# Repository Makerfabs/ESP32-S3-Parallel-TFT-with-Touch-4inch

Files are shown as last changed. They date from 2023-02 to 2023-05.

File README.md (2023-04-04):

# Makerfabs ESP32-S3 Parallel TFT with Touch 4inch

```c++
/*
Version:        V1.1
Author:            Vincent
Create Date:    2023/2/4
Note:
        V1.2：Now support LovyanGFX！
        V1.1: Add example and update readme.
*/
```

[TOC]

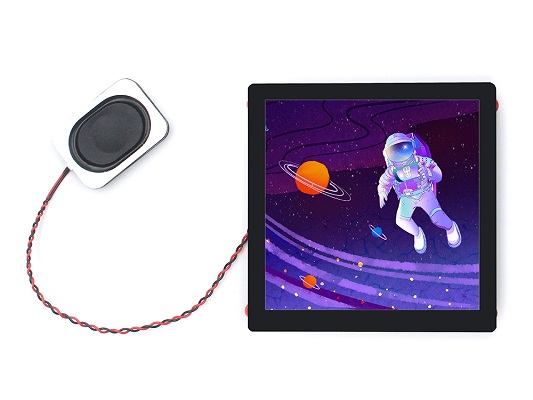
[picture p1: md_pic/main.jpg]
main


# Makerfabs

[Makerfabs home page](https://www.makerfabs.com/)

[Makerfabs Wiki](https://wiki.makerfabs.com/)

# Makerfabs ESP32-S3 Parallel TFT with Touch 4inch

## Intruduce

Product Link ：[ESP32-S3 Parallel TFT with Touch 4.0" 480*480 ST7701](https://www.makerfabs.com/esp32-s3-parallel-tft-with-touch-4-inch.html)

Wiki Link : [ESP32-S3 Parallel 4.0" TFT with Touch](https://wiki.makerfabs.com/ESP32_S3_Parallel_4.0_TFT_with_Touch.html)

The Latest ESP32-S3 4.0 inch display with 480*480 resolution, it integrated display/ touch/ audio speaker/ Lipo charger, to make this product ideal for applications such as IoT controlling, electronic photo frame, etc.

## Feature

- 4 inch RGB IPS display, it communicates with the controller ESP32S3 with 3SPI+RGB5/6/5 interface, with FPS >80;
- 5 points Touch;
- Onboard 16G SD card for storage;
- Lipo battery socket and charger, support any 3.7v lipo battery;
- On board speaker connector. This product is shipped with a 3 ohm 4w, 3528 speaker, the voice loud and clean, suitable for most applications;
- 2x Onboard Mabee connectors, support multiple Mabee/ Grove modules;

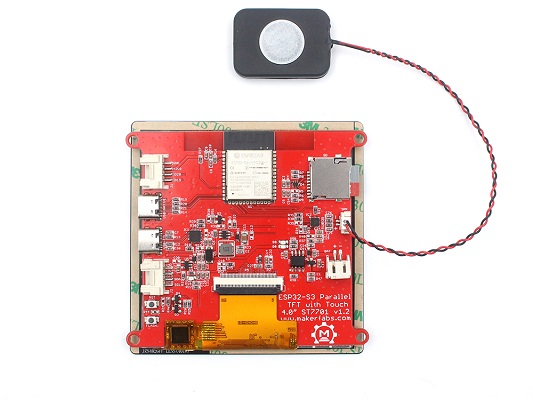
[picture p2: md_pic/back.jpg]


# Code

## Complier Option

- Install board : ESP32 .
- Install libraries：

[ESP32-audioI2S]([GitHub - schreibfaul1/ESP32-audioI2S: Play mp3 files from SD via I2S](https://github.com/schreibfaul1/ESP32-audioI2S))

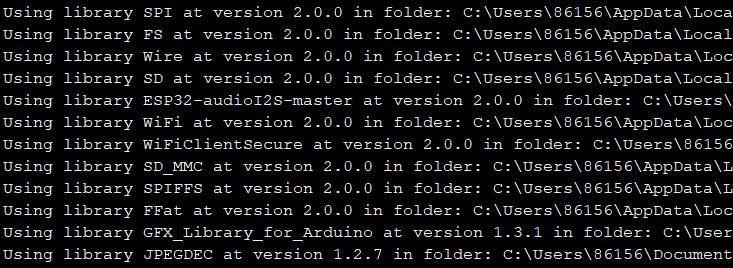
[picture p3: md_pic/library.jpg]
library


- Use type-c use cable connect USB-TTL to PC.
- Select "ESP32-S3 DEV Module"
- Select PSRAM "OPI PSRAM"

"mf_Lvgl" library is modified from Lvgl library (version 8.3.2). 

Please unzip "lib/mf_Lvgl.zip" and copy to arduino library directory.

## Factory test program

\example\esp32s3_4.0_tft_fw_test

You can run this file test if you feel that your hardware is not working properly. 

In addition, it is necessary to decompress the compressed package in the sd_file folder and copy all the pictures and music in it to the TF card.

## Attention

Our Arduino_GFX_library version is 1.3.1, while the latest version is 1.3.4. The two versions are incompatible the running code. Our customer@Tim successfully ran the Arduino_gfx_Library version after modifying the configuration in the code on version 1.3.4.

```
Arduino_DataBus *bus = new Arduino_SWSPI(
    GFX_NOT_DEFINED /* DC */, 1 /* CS */,
    12 /* SCK */, 11 /* MOSI */, GFX_NOT_DEFINED /* MISO */);

Arduino_ESP32RGBPanel *rgbpanel = new Arduino_ESP32RGBPanel(
    45 /* DE */, 4 /* VSYNC */, 5 /* HSYNC */, 21 /* PCLK */,
    39 /* R0 */, 40 /* R1 */, 41 /* R2 */, 42 /* R3 */, 2 /* R4 */,
    0 /* G0 */, 9 /* G1 */, 14 /* G2 */, 47 /* G3 */, 48 /* G4 */, 3 /* G5 */,
    6 /* B0 */, 7 /* B1 */, 15 /* B2 */, 16 /* B3 */, 8 /* B4 */,
    1 /* hsync_polarity */, 10 /* hsync_front_porch */, 8 /* hsync_pulse_width */, 50 /* hsync_back_porch */,
    1 /* vsync_polarity */, 10 /* vsync_front_porch */, 8 /* vsync_pulse_width */, 20 /* vsync_back_porch */);

Arduino_RGB_Display *gfx = new Arduino_RGB_Display(
    480 /* width */, 480 /* height */, rgbpanel, 0 /* rotation */, true /* auto_flush */,
    bus, GFX_NOT_DEFINED /* RST */, st7701_type1_init_operations, sizeof(st7701_type1_init_operations));
```

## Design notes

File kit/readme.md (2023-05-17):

# Makerfabs ESP32-S3 4" Kit

```c++
/*
Version:        V1.1
Author:         Vincent
Create Date:    2023/3/14
Note:

    2023/5/15    V1.1：Change weather API and icons.
*/
```

# Makerfabs

[Makerfabs home page](https://www.makerfabs.com/)

[Makerfabs Wiki](https://wiki.makerfabs.com/)

# Makerfabs ESP32-S3 Parallel TFT with Touch 4inch

## Intruduce

Product Link ：[ESP32-S3 Parallel TFT with Touch 4.0" 480*480 ST7701](https://www.makerfabs.com/esp32-s3-parallel-tft-with-touch-4-inch.html)

Wiki Link : [ESP32-S3 Parallel 4.0" TFT with Touch](https://wiki.makerfabs.com/ESP32_S3_Parallel_4.0_TFT_with_Touch.html)

# 

# Usage

## SD card prepare

Extract "\ESP32-S3-Parallel-TFT-with-Touch-4inch\kit\sd_file.zip"

Copy all files in sd_file to the SD card, making sure that wifi.txt,mp3,jpg are in the root directory.

The SD card shipped with the factory has already downloaded the necessary files.

Of course you can put your pictures and music on the SD card.

The image should be in.jpg format, preferably 480 by 480 pixels.

Music required format.mp3.

And edit "wifi.txt", change your own WiFi ssid and WiFi password.

```
SSID:[YOUR SSID]
PASSWORD:[YOUR PWD]
# Please change your own wifi setting in "[]".
# WIFI name and password can only contain letters and numbers, the program is not fully compatible with special characters.
```

Insert SD card.

## Music Frame

JPG pictures and MP3 music in the root directory of the SD card are automatically played.

## Global Weather

Click on the flags of different countries to toggle different periods and show the weather in the capital.

## TVOC Monitor

Mabee CO2 needs to be connected to the I2C interface.

Displays TVOC sensor measurements and provides a web page to access.

You need to set up WiFi to use it.

## Thermal Camera

You need to connect Mabee MLX90640 to the I2C interface

Simple thermal imaging camera.

# Code

## Bin Burn

Select ESP32 S3

0x0                    kit.ino.bootloader.bin 
0x8000             kit.ino.partitions.bin 
0xe000             boot_app0.bin 
0x10000           kit.ino.bin 

## Complier Option

Install board : ESP32 2.0.5

Install libraries from Library Manager：

- Using 1.3.1  Version  GFX_Library_for_Arduino

- Using 1.0.2  Version  TAMC_GT911

- Using 6.20.1  Version  ArduinoJson

- Using 1.0.2  Version  Adafruit_MLX90640

- Using 1.14.1  Version  Adafruit_BusIO

- Using 2.0.0  Version  Adafruit_SGP30_Sensor

- Using 2.2.0  Version  Adafruit_SHT31_Library

- Using 1.2.8  Version  JPEGDEC

Install libraries from Github：

- Using 2.0.0  Version  ESP32-audioI2S-master

- Using 1.2.3  Version  ESPAsyncWebServer-masterr 

- Using 1.1.1  Version  AsyncTCP-master

Use type-c use cable connect USB-TTL to PC.

Select "ESP32-S3 DEV Module"

Select PSRAM "OPI PSRAM"

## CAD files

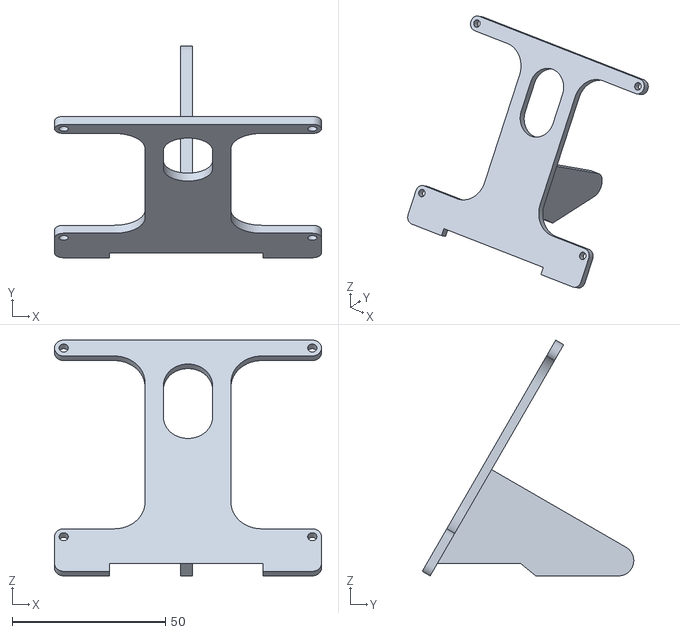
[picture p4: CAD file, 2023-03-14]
kit/3d_file/stand.stl
87.0 x 68.9 x 76.8

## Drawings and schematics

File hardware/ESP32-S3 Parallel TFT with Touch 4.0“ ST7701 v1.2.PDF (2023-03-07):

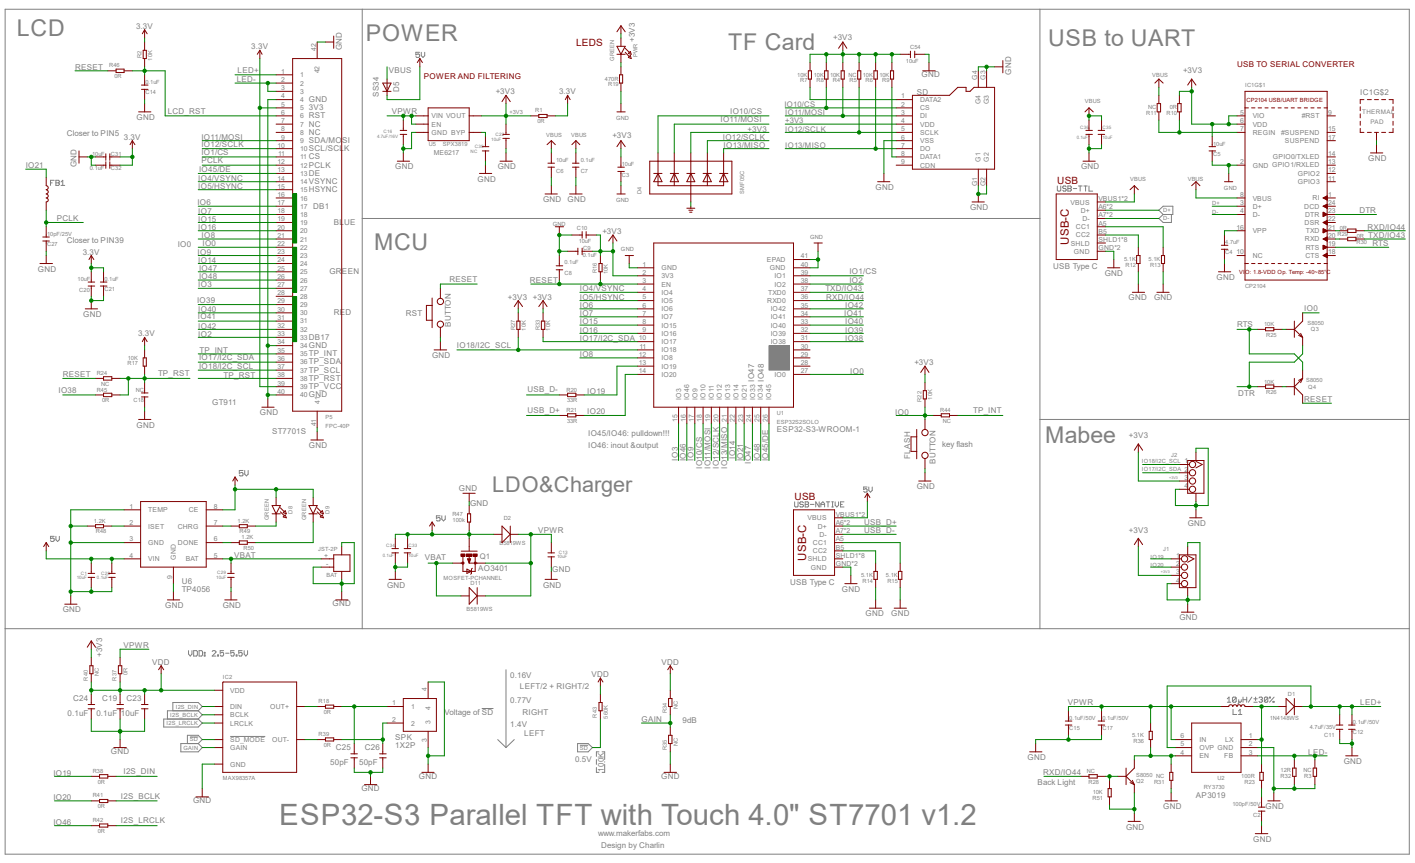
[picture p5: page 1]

USB Type C TF Card

USB TO SERIAL CONVERTER

VIO: 1.8-VDD Op. Temp: -40~85°C USB⁻C USB⁻C

key flash ESP32-S3 Parallel TFT with Touch 4.0" ST7701 v1.2

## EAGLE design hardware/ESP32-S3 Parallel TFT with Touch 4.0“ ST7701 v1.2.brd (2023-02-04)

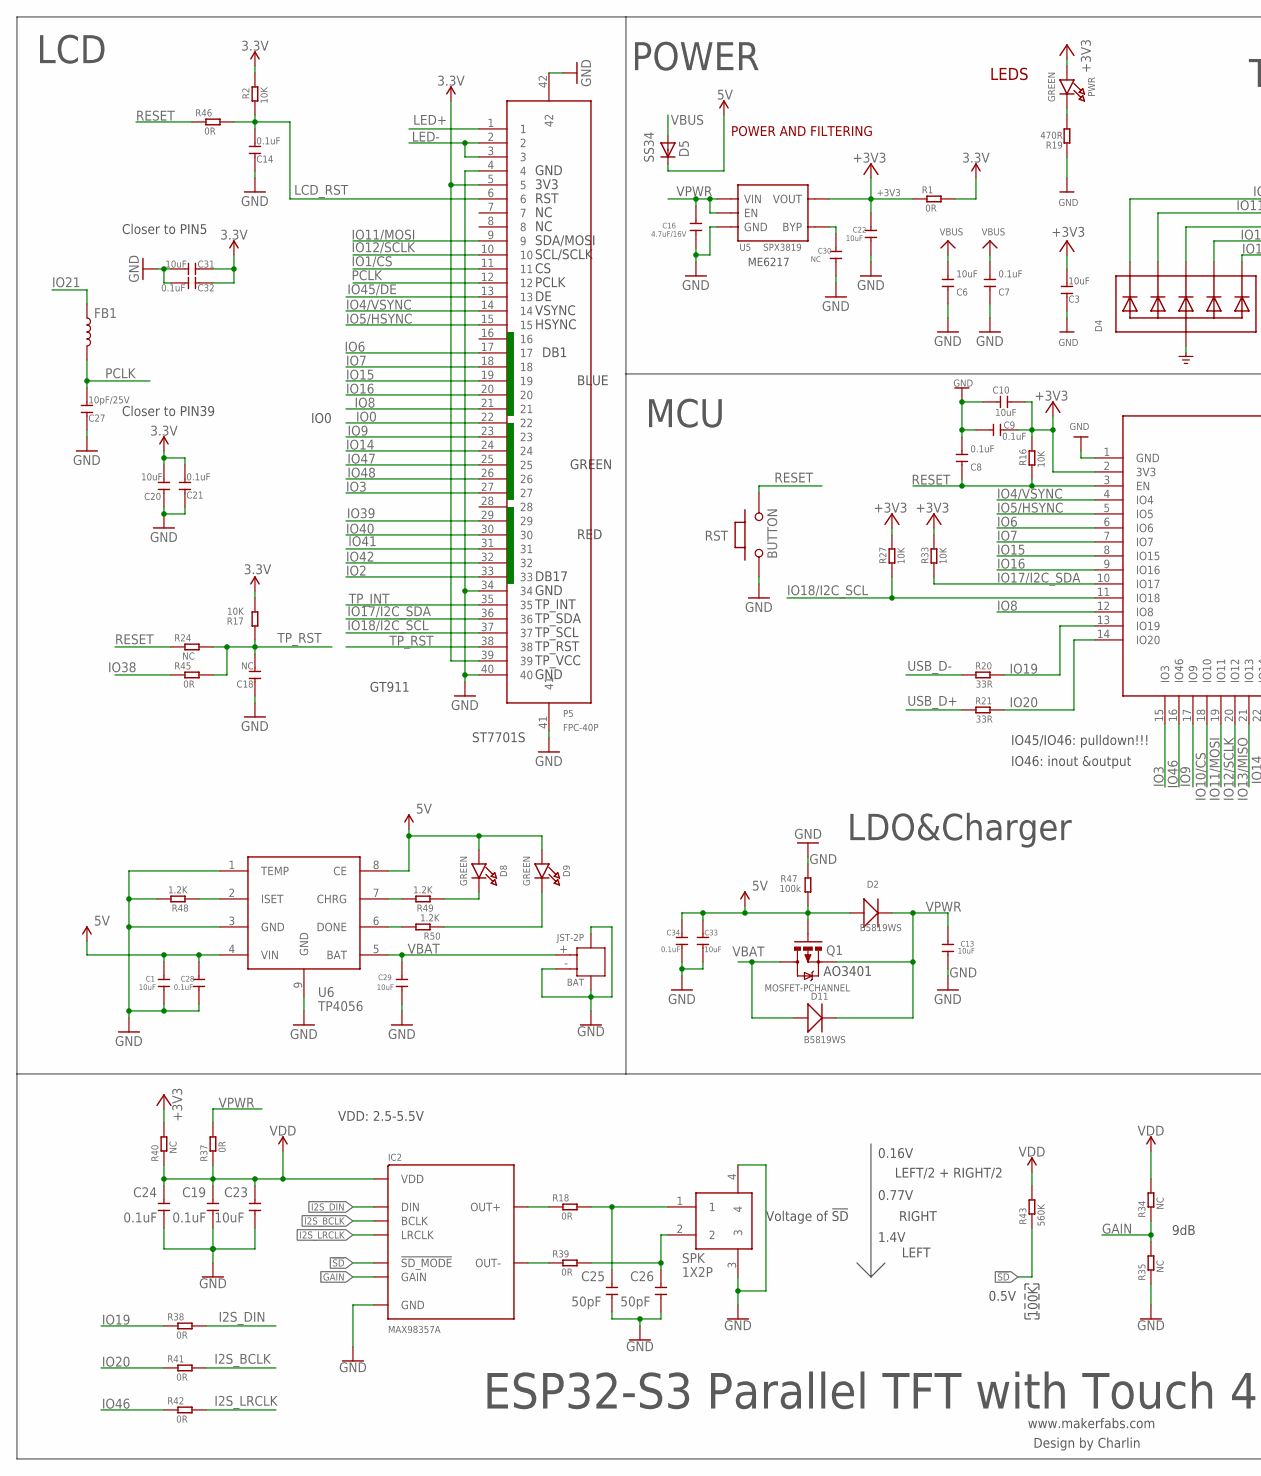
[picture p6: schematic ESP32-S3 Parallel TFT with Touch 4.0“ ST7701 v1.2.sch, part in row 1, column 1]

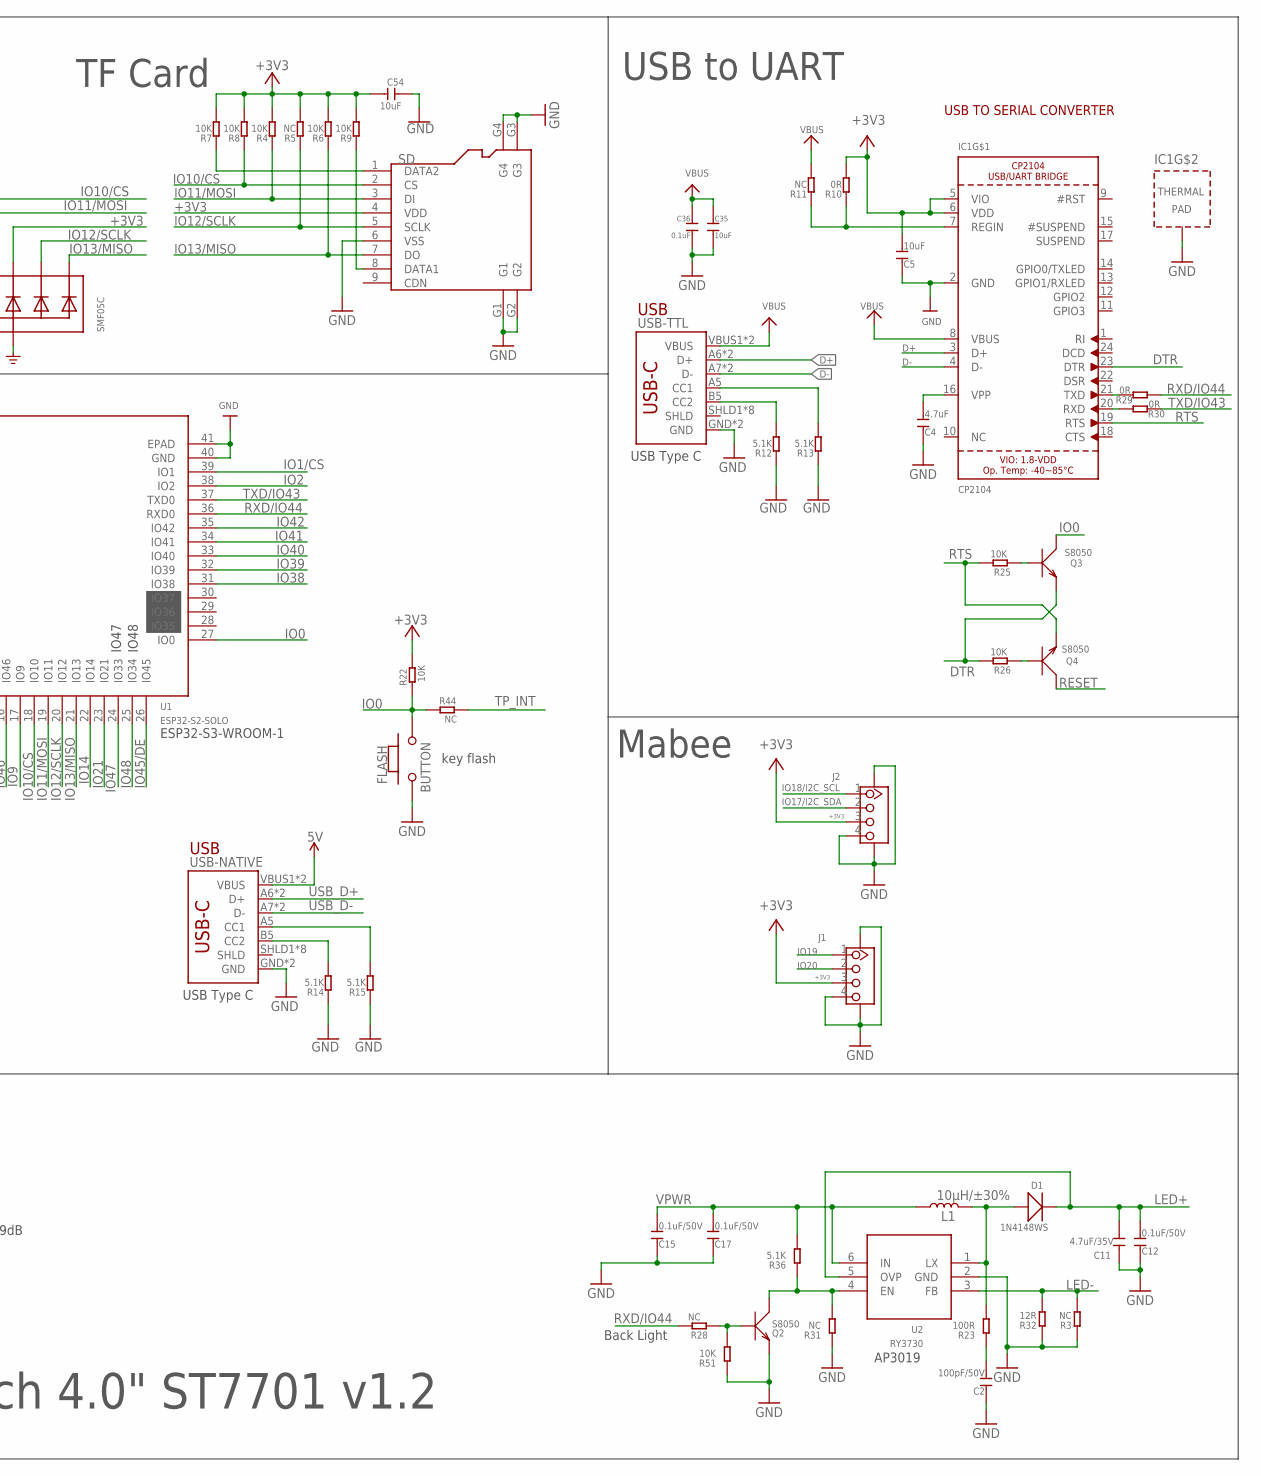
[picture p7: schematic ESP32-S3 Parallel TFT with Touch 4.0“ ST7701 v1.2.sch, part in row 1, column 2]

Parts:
BAT: JST-2P; HW2-SMD-2.0-90D
C1, C13, C22, C23, C29, C33, C35: 10uF; 0603
C2: 100pF/50V; DISCRETE_C0603
C3, C5, C6, C10, C20, C31, C54: 10uF; DISCRETE_C0603
C4: 4.7uF; DISCRETE_C0603
C7, C8, C9, C14, C21, C32: 0.1uF; DISCRETE_C0603
C11: 4.7uF/35V; DISCRETE_C1206
C12, C15, C17: 0.1uF/50V; DISCRETE_C0603
C16: 4.7uF/16V; 0603
C18: NC; DISCRETE_C0603
C19, C24, C28, C34, C36: 0.1uF; 0603
C25, C26: 50pF; 0603
C27: 10pF/25V; DISCRETE_C0603
C30: NC; 0603
D1: 1N4148WS; SOD323
D2, D11: B5819WS; SOD323
D4: SMF05C; SOT363
D5: SS34; DO-214AC
D8, D9: GREEN; CHIPLED_0805_NOOUTLINE
FB1: INDUCTORFB-30OHM; 0603
FLASH: BUTTON; 157SW
IC1: CP2104; QFN24_4MM_SMSC
IC2: MAX98357A; TQFN-16
J1, J2: GROVE-CONNECTOR-SMD'90D'; HW4-SMD-2.0-90D
L1: 10µH/±30%; CR54
P5: FPC-40P; SMD42-50P-2560L490W
PWR: GREEN; CHIPLED_0805_NOOUTLINE
Q1: MOSFET-PCHANNEL; SOT23-3
Q2, Q3, Q4: S8050; SOT23
R1, R18, R29, R30, R37, R38, R39, R41, R42, R45, R46: 0R; R0603
R2, R16, R22, R25, R26, R27, R33: 10K; R0603
R3, R5, R11, R28, R31: NC; DISCRETE_R0603
R4, R6, R7, R8, R9, R17, R51: 10K; DISCRETE_R0603
R10: 0R; DISCRETE_R0603
R12, R13, R14, R15, R36: 5.1K; DISCRETE_R0603
R19: 470R; DISCRETE_R0603
R20, R21: 33R; R0603
R23: 100R; DISCRETE_R0603
R24, R34, R35, R40, R44: NC; R0603
R32: 12R; DISCRETE_R0603
R43: 560K; R0603
R47: 100k; R0603
R48, R49, R50: 1.2K; R0603
RST: BUTTON; 157SW
SD: HOLDER-MICROSD-9P; 9P-SMD-W/-RING
SPK: 1X2P; 1X2P-SMT1.25MM
U1: ESP32­S2­SOLO; ESP32-­S2-­SOLO
U2: RY3730; SOT23-6
U5: SPX3819; SOT23-5
U6: TP4056; SOP8-1.27P
USB-NATIVE: USB_C5; USB-C-16P-5
USB-TTL: USB_C5; USB-C-16P-5

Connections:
3.3V: C20.2, C21.2, C31.1, C32.1, P5.5, P5.39, R1.2, R2.2, R17.2
5V: C1.1, C28.1, C33.2, C34.1, D2.+, D5.C, D8.A, D9.A, Q1.1 (G), R47.1, U6.4 (VIN), U6.8 (CE), USB-NATIVE.VBUS1 (VBUS), USB-NATIVE.VBUS2 (VBUS)
!SD: IC2.P$4 (!SD_MODE), R43.1
+3V3: C3.2, C5.2, C9.1, C10.1, C22.1, C54.2, D4.4 (C3), IC1.5 (VIO), IC1.6 (VDD), J1.3, J2.3, PWR.A, R1.1, R4.2, R5.2, R6.2, R7.2, R8.2, R9.2, R10.2, R16.2, R22.2, R27.2, R33.2, R40.2, SD.4 (VDD), U1.2 (3V3), U5.5 (VOUT)
D+: IC1.3 (D+), USB-TTL.A6 (D+), USB-TTL.B6 (D+)
D-: IC1.4 (D-), USB-TTL.A7 (D-), USB-TTL.B7 (D-)
DTR: IC1.23 (DTR), Q3.2 (E), R26.2
GAIN: IC2.P$2 (GAIN), R34.1, R35.2
GND: BAT.3, BAT.4, BAT.- (2), C1.2, C2.1, C3.1, C4.1, C5.1, C6.1, C7.1, C8.2, C9.2, C10.2, C11.1, C12.1, C13.1, C14.1, C15.1, C16.2, C17.1, C18.1, C19.1, C20.1, C21.1, C22.2, C23.1, C24.1, C25.1, C26.1, C27.1, C28.2, C29.2, C30.2, C31.2, C32.2, C33.1, C34.2, C35.1, C36.2, C54.1, D4.2 (A), FLASH.1, IC1.2 (GND), IC1.THERM (TP), IC2.P$3 (GND), IC2.P$11 (GND), IC2.P$15 (GND), IC2.P$EP (GND), J1.4, J1.SS1, J1.SS2, J2.4, J2.SS1, J2.SS2, P5.4, P5.34, P5.40, P5.41, P5.42, Q2.2 (E), R3.1, R12.1, R13.1, R14.1, R15.1, R19.1, R31.1, R32.1, R35.1, R47.2, R48.2, R51.1, RST.1, SD.6 (VSS), SD.G1, SD.G2, SD.G3, SD.G4, SPK.3, SPK.4, U1.1 (GND), U1.40 (GND), U1.41 (EPAD), U2.2 (GND), U5.2 (GND), U6.1 (TEMP), U6.3 (GND), U6.9 (GND), USB-NATIVE.GND, USB-NATIVE.GND2 (GND), USB-TTL.GND, USB-TTL.GND2 (GND)
I2S_BCLK: IC2.P$16 (BCLK), R41.2
I2S_DIN: IC2.P$1 (DIN), R38.2
I2S_LRCLK: IC2.P$14 (LRCLK), R42.2
IO0: FLASH.2, P5.22, Q3.3 (C), R22.1, R44.1, U1.27 (IO0)
IO1/CS: P5.11, U1.39 (IO1)
IO2: P5.33, U1.38 (IO2)
IO3: P5.27, U1.15 (IO3)
IO4/VSYNC: P5.14, U1.4 (IO4)
IO5/HSYNC: P5.15, U1.5 (IO5)
IO6: P5.17, U1.6 (IO6)
IO7: P5.18, U1.7 (IO7)
IO8: P5.21, U1.12 (IO8)
IO9: P5.23, U1.17 (IO9)
IO10/CS: D4.1 (C1), R8.1, SD.2 (CS), U1.18 (IO10)
IO11/MOSI: D4.3 (C2), P5.9, R4.1, SD.3 (DI), U1.19 (IO11)
IO12/SCLK: D4.5 (C4), P5.10, R5.1, SD.5 (SCLK), U1.20 (IO12)
IO13/MISO: D4.6 (C5), R6.1, SD.7 (DO), U1.21 (IO13)
IO14: P5.24, U1.22 (IO14)
IO15: P5.19, U1.8 (IO15)
IO16: P5.20, U1.9 (IO16)
IO17/I2C_SDA: J2.2, P5.36, R33.1, U1.10 (IO17)
IO18/I2C_SCL: J2.1, P5.37, R27.1, U1.11 (IO18)
IO19: J1.1, R20.2, R38.1, U1.13 (IO19)
IO20: J1.2, R21.2, R41.1, U1.14 (IO20)
IO21: FB1.1, U1.23 (IO21)
IO38: R45.1, U1.31 (IO38)
IO39: P5.29, U1.32 (IO39)
IO40: P5.30, U1.33 (IO40)
IO41: P5.31, U1.34 (IO41)
IO42: P5.32, U1.35 (IO42)
IO45/DE: P5.13, U1.26 (IO45)
IO46: R42.1, U1.16 (IO46)
IO47: P5.25, U1.24 (IO33)
IO48: P5.26, U1.25 (IO34)
LCD_RST: C14.2, P5.6, R2.1, R46.2
LED+: C11.2, C12.2, D1.-, P5.1, U2.5 (OVP)
LED-: P5.2, P5.3, R3.2, R32.2, U2.3 (FB)
unnamed: C4.2, IC1.16 (VPP)
unnamed: Q4.1 (B), R26.1
unnamed: Q3.1 (B), R25.1
unnamed: IC2.P$9 (OUT+), R18.1
unnamed: R15.2, USB-NATIVE.A5 (CC1)
unnamed: PWR.C, R19.2
unnamed: Q2.1 (B), R28.1, R51.2
unnamed: R13.2, USB-TTL.A5 (CC1)
unnamed: R12.2, USB-TTL.B5 (CC2)
unnamed: IC1.7 (REGIN), R10.1, R11.1
unnamed: IC2.P$10 (OUT-), R39.1
unnamed: R14.2, USB-NATIVE.B5 (CC2)
unnamed: C25.2, R18.2, SPK.1
unnamed: C26.2, R39.2, SPK.2
unnamed: D1.+, L1.P$2 (2), R23.2, U2.1 (LX)
unnamed: IC1.21 (TXD), R29.2
unnamed: IC1.20 (RXD), R30.2
unnamed: C2.2, R23.1
unnamed: R48.1, U6.2 (ISET)
unnamed: Q2.3 (C), R31.2, R36.1, U2.4 (EN)
unnamed: R49.2, U6.7 (CHRG)
unnamed: R50.2, U6.6 (DONE)
unnamed: D8.C, R49.1
unnamed: D9.C, R50.1
unnamed: R7.1, SD.1 (DATA2)
unnamed: R9.1, SD.8 (DATA1)
unnamed: C30.1, U5.4 (BYP)
PCLK: C27.2, FB1.2, P5.12
RESET: C8.1, Q4.3 (C), R16.1, R24.1, R46.1, RST.2, U1.3 (EN)
RTS: IC1.19 (RTS), Q4.2 (E), R25.2
RXD/IO44: R28.2, R29.1, U1.36 (RXD0)
TP_INT: P5.35, R44.2
TP_RST: C18.2, P5.38, R17.1, R24.2, R45.2
TXD/IO43: R30.1, U1.37 (TXD0)
USB_D+: R21.1, USB-NATIVE.A6 (D+), USB-NATIVE.B6 (D+)
USB_D-: R20.1, USB-NATIVE.A7 (D-), USB-NATIVE.B7 (D-)
VBAT: BAT.+ (1), C29.1, D11.+, Q1.3 (D), U6.5 (BAT)
VBUS: C6.2, C7.2, C35.2, C36.1, D5.A, IC1.8 (VBUS), R11.2, USB-TTL.VBUS1 (VBUS), USB-TTL.VBUS2 (VBUS)
VDD: C19.2, C23.2, C24.2, IC2.P$7 (VDD), IC2.P$8 (VDD), R34.2, R37.1, R40.1, R43.2
VPWR: C13.2, C15.2, C16.1, C17.2, D2.-, D11.-, L1.P$1 (1), Q1.2 (S), R36.2, R37.2, U2.6 (IN), U5.1 (VIN), U5.3 (EN)

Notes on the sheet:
www.makerfabs.com
Design by Charlin
USB
LEDS
POWER AND FILTERING
USB TO SERIAL CONVERTER
key flash
ESP32-S3 Parallel TFT with Touch 4.0" ST7701 v1.2
POWER
USB to UART
USB Type C
TF Card
GT911
Back Light
IO45/IO46: pulldown!!!
IO46: inout &output
Mabee
LCD
MCU
ESP32-S3-WROOM-1
IO47
IO48
Closer to PIN5
3V3
DB1
RST
TP_INT
SDA/MOSI
SCL/SCLK
PCLK
VSYNC
HSYNC
TP_SDA
TP_SCL
TP_RST
TP_VCC
ST7701S
GND
DB17
BLUE

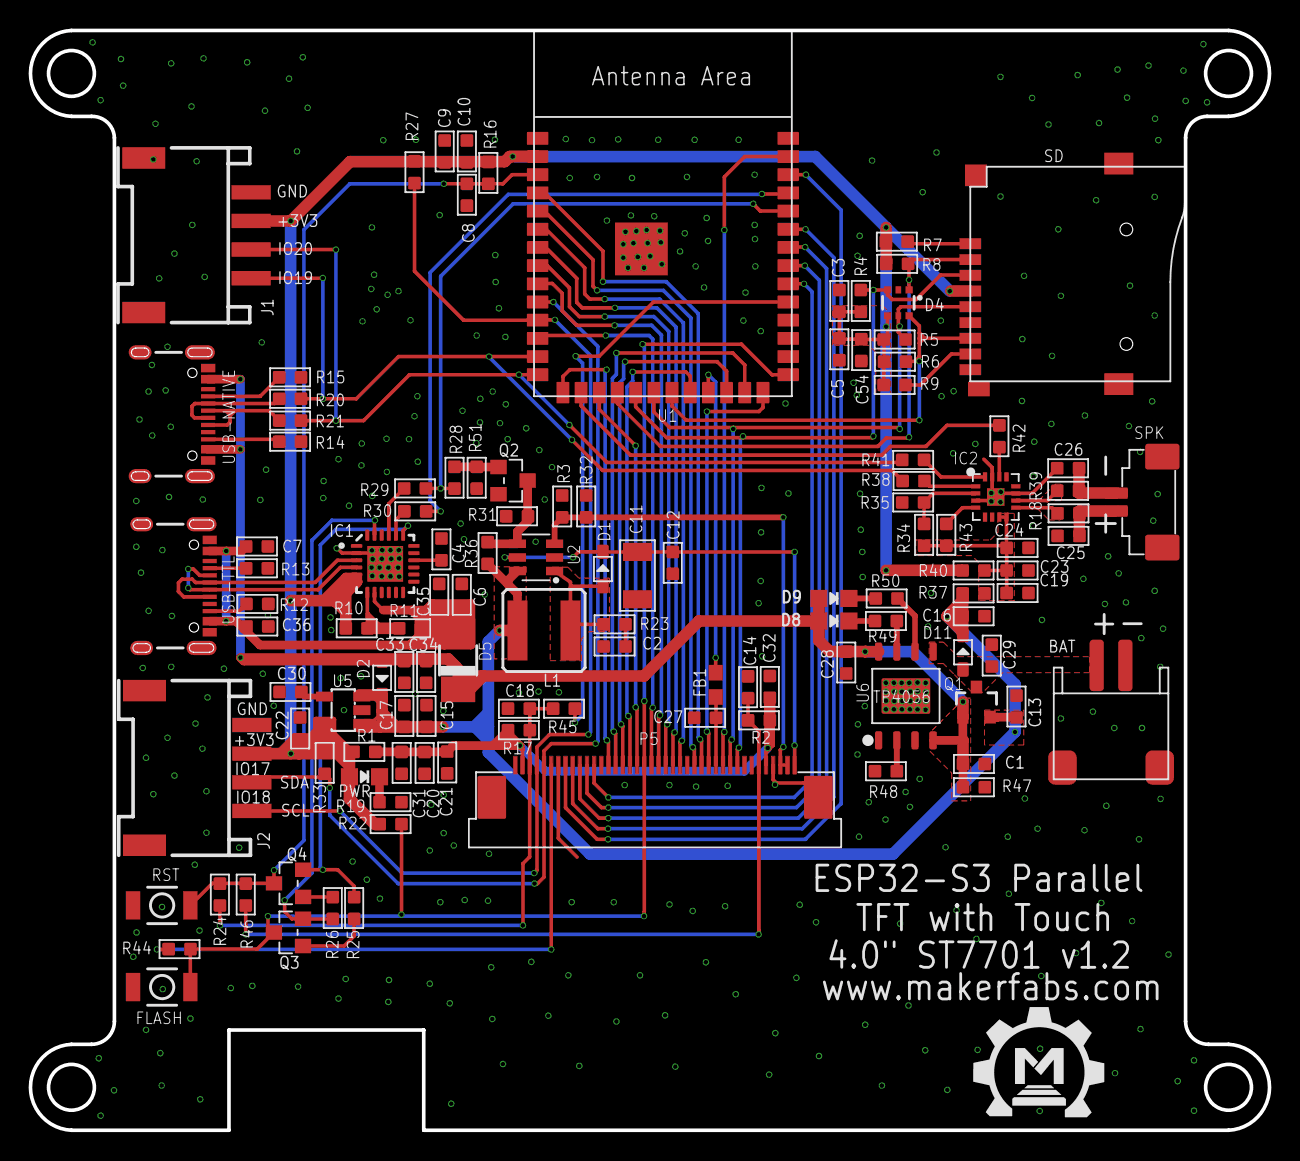
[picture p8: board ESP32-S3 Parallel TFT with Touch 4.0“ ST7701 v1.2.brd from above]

Board: 2 copper layers, 86.5 x 76.8 mm, 119 parts (0 on the bottom side), 86 nets.

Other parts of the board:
U$1: MAKERFABS_0.3

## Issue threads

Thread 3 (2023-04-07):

Arduino_ST7701_RGBPanel library missing?

puddletowntom, 2023-04-07:
I cant seem to find the ST7701 library. Are you sure its in your github repository.

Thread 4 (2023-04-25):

rotation values 1 and 3 do not work

rajiv-obhcare, 2023-04-25:
```
Arduino_ST7701_RGBPanel *gfx = new Arduino_ST7701_RGBPanel(
    bus, GFX_NOT_DEFINED /* RST */, 0 /* rotation */, true /* IPS */,
    480 /* width */, 480 /* height */, st7701_type1_init_operations,
    sizeof(st7701_type1_init_operations), true /* BGR */);

```

In the above code, of the 4 rotation values 0,1,2,3. Only 0 and 2 works. 3 and 4 do not work. How do I fix it?

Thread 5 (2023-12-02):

Compiling LVGL Example on Mac OSX

j-raghavan, 2023-12-02:
Hello,

I recently purchased ESP32-S3 Parallel TFT 4 inch ST7701, I am trying to compile the Example on Mac OSX and I fail to get it compile. Getting myriad of issues. Like these

```
In file included from /Users/jayasimha/Documents/Arduino/libraries/GFX_Library_for_Arduino/src/Arduino_GFX_Library.h:4,
                 from /Users/jayasimha/Workspace/arduino/playground/esp32/ESP32-S3-Parallel-TFT-with-Touch-4inch/example/esp32s3_4.0_tft_fw_test/esp32s3_4.0_tft_fw_test.ino:6:
/Users/jayasimha/Documents/Arduino/libraries/GFX_Library_for_Arduino/src/Arduino_DataBus.h:182:13: error: 'i80_device_list' has not been declared
  182 |   LIST_HEAD(i80_device_list, lcd_panel_io_i80_t)
      |             ^~~~~~~~~~~~~~~
/Users/jayasimha/Documents/Arduino/libraries/GFX_Library_for_Arduino/src/Arduino_DataBus.h:182:3: error: ISO C++ forbids declaration of 'LIST_HEAD' with no type [-fpermissive]
  182 |   LIST_HEAD(i80_device_list, lcd_panel_io_i80_t)
      |   ^~~~~~~~~
/Users/jayasimha/Documents/Arduino/libraries/GFX_Library_for_Arduino/src/Arduino_DataBus.h:182:48: error: expected ';' at end of member declaration
  182 |   LIST_HEAD(i80_device_list, lcd_panel_io_i80_t)
      |                                                ^
      |                                                 ;
/Users/jayasimha/Documents/Arduino/libraries/GFX_Library_for_Arduino/src/Arduino_DataBus.h:183:3: error: 'device_list' does not name a type
  183 |   device_list; // Head of i80 device list
      |   ^~~~~~~~~~~
/Users/jayasimha/Documents/Arduino/libraries/GFX_Library_for_Arduino/src/Arduino_DataBus.h:217:3: error: ISO C++ forbids declaration of 'LIST_ENTRY' with no type [-fpermissive]
  217 |   LIST_ENTRY(lcd_panel_io_i80_t)
      |   ^~~~~~~~~~
/Users/jayasimha/Documents/Arduino/libraries/GFX_Library_for_Arduino/src/Arduino_DataBus.h:217:32: error: expected ';' at end of member declaration
  217 |   LIST_ENTRY(lcd_panel_io_i80_t)
      |                                ^
      |                                 ;
/Users/jayasimha/Documents/Arduino/libraries/GFX_Library_for_Arduino/src/Arduino_DataBus.h:218:3: error: 'device_list_entry' does not name a type
  218 |   device_list_entry; // Entry of i80 device list
      |   ^~~~~~~~~~~~~~~~~
In file included from /Users/jayasimha/Documents/Arduino/libraries/GFX_Library_for_Arduino/src/Arduino_GFX_Library.h:19:
/Users/jayasimha/Documents/Arduino/libraries/GFX_Library_for_Arduino/src/databus/Arduino_ESP32RGBPanel.h:43:3: error: 'esp_lcd_rgb_panel_frame_trans_done_cb_t' does not name a type; did you mean 'esp_lcd_panel_io_color_trans_done_cb_t'?
   43 |   esp_lcd_rgb_panel_frame_trans_done_cb_t on_frame_trans_done; // Callback, invoked after frame trans done
      |   ^~~~~~~~~~~~~~~~~~~~~~~~~~~~~~~~~~~~~~~
      |   esp_lcd_panel_io_color_trans_done_cb_t
/Users/jayasimha/Workspace/arduino/playground/esp32/ESP32-S3-Parallel-TFT-with-Touch-4inch/example/esp32s3_4.0_tft_fw_test/esp32s3_4.0_tft_fw_test.ino:70:1: error: no matching function for call to 'Arduino_ESP32RGBPanel::Arduino_ESP32RGBPanel(int, int, int, int, int, int, int, int, int, int, int, int, int, int, int, int, int, int, int, int, int, int, int)'
   70 | );
      | ^
/Users/jayasimha/Documents/Arduino/libraries/GFX_Library_for_Arduino/src/databus/Arduino_ESP32RGBPanel.h:59:3: note: candidate: 'Arduino_ESP32RGBPanel::Arduino_ESP32RGBPanel(int8_t, int8_t, int8_t, int8_t, int8_t, int8_t, int8_t, int8_t, int8_t, int8_t, int8_t, int8_t, int8_t, int8_t, int8_t, int8_t, int8_t, int8_t, int8_t, int8_t, uint16_t, uint16_t, uint16_t, uint16_t, uint16_t, uint16_t, uint16_t, uint16_t, uint16_t, int32_t, bool, uint16_t, uint16_t)'
   59 |   Arduino_ESP32RGBPanel(
      |   ^~~~~~~~~~~~~~~~~~~~~
/Users/jayasimha/Documents/Arduino/libraries/GFX_Library_for_Arduino/src/databus/Arduino_ESP32RGBPanel.h:59:3: note:   candidate expects 33 arguments, 23 provided
/Users/jayasimha/Documents/Arduino/libraries/GFX_Library_for_Arduino/src/databus/Arduino_ESP32RGBPanel.h:56:7: note: candidate: 'constexpr Arduino_ESP32RGBPanel::Arduino_ESP32RGBPanel(const Arduino_ESP32RGBPanel&)'
   56 | class Arduino_ESP32RGBPanel
      |       ^~~~~~~~~~~~~~~~~~~~~
/Users/jayasimha/Documents/Arduino/libraries/GFX_Library_for_Arduino/src/databus/Arduino_ESP32RGBPanel.h:56:7: note:   candidate expects 1 argument, 23 provided
/Users/jayasimha/Documents/Arduino/libraries/GFX_Library_for_Arduino/src/databus/Arduino_ESP32RGBPanel.h:56:7: note: candidate: 'constexpr Arduino_ESP32RGBPanel::Arduino_ESP32RGBPanel(Arduino_ESP32RGBPanel&&)'
/Users/jayasimha/Documents/Arduino/libraries/GFX_Library_for_Arduino/src/databus/Arduino_ESP32RGBPanel.h:56:7: note:   candidate expects 1 argument, 23 provided
/Users/jayasimha/Workspace/arduino/playground/esp32/ESP32-S3-Parallel-TFT-with-Touch-4inch/example/esp32s3_4.0_tft_fw_test/esp32s3_4.0_tft_fw_test.ino:72:1: error: 'Arduino_ST7701_RGBPanel' does not name a type; did you mean 'Arduino_ESP32RGBPanel'?
   72 | Arduino_ST7701_RGBPanel *gfx = new Arduino_ST7701_RGBPanel(
      | ^~~~~~~~~~~~~~~~~~~~~~~
      | Arduino_ESP32RGBPanel
/Users/jayasimha/Workspace/arduino/playground/esp32/ESP32-S3-Parallel-TFT-with-Touch-4inch/example/esp32s3_4.0_tft_fw_test/esp32s3_4.0_tft_fw_test.ino: In function 'int jpegDrawCallback(JPEGDRAW*)':
/Users/jayasimha/Workspace/arduino/playground/esp32/ESP32-S3-Parallel-TFT-with-Touch-4inch/example/esp32s3_4.0_tft_fw_test/esp32s3_4.0_tft_fw_test.ino:122:3: error: 'gfx' was not declared in this scope
  122 |   gfx->draw16bitBeRGBBitmap(pDraw->x, pDraw->y, pDraw->pPixels, pDraw->iWidth, pDraw->iHeight);
      |   ^~~
/Users/jayasimha/Workspace/arduino/playground/esp32/ESP32-S3-Parallel-TFT-with-Touch-4inch/example/esp32s3_4.0_tft_fw_test/esp32s3_4.0_tft_fw_test.ino: In function 'void imageDisplay(int)':
/Users/jayasimha/Workspace/arduino/playground/esp32/ESP32-S3-Parallel-TFT-with-Touch-4inch/example/esp32s3_4.0_tft_fw_test/esp32s3_4.0_tft_fw_test.ino:149:38: error: 'gfx' was not declared in this scope
  149 |                0 /* x */, 0 /* y */, gfx->width() /* widthLimit */, gfx->height() /* heightLimit */);
      |                                      ^~~
/Users/jayasimha/Workspace/arduino/playground/esp32/ESP32-S3-Parallel-TFT-with-Touch-4inch/example/esp32s3_4.0_tft_fw_test/esp32s3_4.0_tft_fw_test.ino: In function 'void setup()':
/Users/jayasimha/Workspace/arduino/playground/esp32/ESP32-S3-Parallel-TFT-with-Touch-4inch/example/esp32s3_4.0_tft_fw_test/esp32s3_4.0_tft_fw_test.ino:225:3: error: 'gfx' was not declared in this scope
  225 |   gfx->begin();
      |   ^~~
Multiple libraries were found for "SD.h"
  Used: /Users/jayasimha/Library/Arduino15/packages/esp32/hardware/esp32/3.0.0-alpha2/libraries/SD
  Not used: /Users/jayasimha/Library/Arduino15/libraries/SDOLD
exit status 1

Compilation error: no matching function for call to 'Arduino_ESP32RGBPanel::Arduino_ESP32RGBPanel(int, int, int, int, int, int, int, int, int, int, int, int, int, int, int, int, int, int, int, int, int, int, int)'
```

Could some one help me point to a guide that can help me compile the sample code and help me get started developing on this board?

Thanks,
JR

rubenvillarnet, 2023-12-07:
I'm having the exact issues as @j-raghavan. This is my environment info:
- OS: macOS 12.7.1
- Arduino IDE 2.2.1
- I've followed the steps of this guide: [https://wiki.makerfabs.com/MaTouch_S3_Parallel_4.0_TFT_with_Touch.html](https://wiki.makerfabs.com/MaTouch_S3_Parallel_4.0_TFT_with_Touch.html)
  - I’ve installed the ESP32 Board SDK
  - I’ve installed the version 1.0.2 of TAMC_GT911.
  - I’ve set the parameters as in the screenshot.
  - I’ve installed the version 1.3.1 of GFX_Library_for_Arduino.
  - I’ve downloaded and installed MF_Lvg library.

When I try to verify any example I always encounter these errors:

```
In file included from /Users/ru/Documents/Arduino/libraries/GFX_Library_for_Arduino/src/Arduino_GFX_Library.h:4,
                 from /Users/ru/Downloads/ESP32-S3-Parallel-TFT-with-Touch-4inch-main/example/LvglWidgets/LvglWidgets.ino:28:
/Users/ru/Documents/Arduino/libraries/GFX_Library_for_Arduino/src/Arduino_DataBus.h:161:13: error: 'i80_device_list' has not been declared
  161 |   LIST_HEAD(i80_device_list, lcd_panel_io_i80_t)
      |             ^~~~~~~~~~~~~~~
/Users/ru/Documents/Arduino/libraries/GFX_Library_for_Arduino/src/Arduino_DataBus.h:161:3: error: ISO C++ forbids declaration of 'LIST_HEAD' with no type [-fpermissive]
  161 |   LIST_HEAD(i80_device_list, lcd_panel_io_i80_t)
      |   ^~~~~~~~~
/Users/ru/Documents/Arduino/libraries/GFX_Library_for_Arduino/src/Arduino_DataBus.h:161:48: error: expected ';' at end of member declaration
  161 |   LIST_HEAD(i80_device_list, lcd_panel_io_i80_t)
      |                                                ^
      |                                                 ;
/Users/ru/Documents/Arduino/libraries/GFX_Library_for_Arduino/src/Arduino_DataBus.h:162:3: error: 'device_list' does not name a type
  162 |   device_list; // Head of i80 device list
      |   ^~~~~~~~~~~
/Users/ru/Documents/Arduino/libraries/GFX_Library_for_Arduino/src/Arduino_DataBus.h:196:3: error: ISO C++ forbids declaration of 'LIST_ENTRY' with no type [-fpermissive]
  196 |   LIST_ENTRY(lcd_panel_io_i80_t)
      |   ^~~~~~~~~~
/Users/ru/Documents/Arduino/libraries/GFX_Library_for_Arduino/src/Arduino_DataBus.h:196:32: error: expected ';' at end of member declaration
  196 |   LIST_ENTRY(lcd_panel_io_i80_t)
      |                                ^
      |                                 ;
/Users/ru/Documents/Arduino/libraries/GFX_Library_for_Arduino/src/Arduino_DataBus.h:197:3: error: 'device_list_entry' does not name a type
  197 |   device_list_entry; // Entry of i80 device list
      |   ^~~~~~~~~~~~~~~~~
In file included from /Users/ru/Documents/Arduino/libraries/GFX_Library_for_Arduino/src/Arduino_GFX_Library.h:14:
/Users/ru/Documents/Arduino/libraries/GFX_Library_for_Arduino/src/databus/Arduino_ESP32RGBPanel.h:43:3: error: 'esp_lcd_rgb_panel_frame_trans_done_cb_t' does not name a type; did you mean 'esp_lcd_panel_io_color_trans_done_cb_t'?
   43 |   esp_lcd_rgb_panel_frame_trans_done_cb_t on_frame_trans_done; // Callback, invoked after frame trans done
      |   ^~~~~~~~~~~~~~~~~~~~~~~~~~~~~~~~~~~~~~~
      |   esp_lcd_panel_io_color_trans_done_cb_t

exit status 1

Compilation error: exit status 1
```

FlamingFury321, 2024-08-22:
I'm not sure if this is still helpful but this error can be solved by downgrading the board managers version for the esp32 back to V2.x.x from V3.x.x. At least in my case it solved the problem.

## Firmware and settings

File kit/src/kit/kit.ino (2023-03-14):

#include "config.h"
#include "page.h"

Arduino_ESP32RGBPanel *bus = new Arduino_ESP32RGBPanel(1 /* CS */, 12 /* SCK */, 11 /* SDA */, 45 /* DE */, 4 /* VSYNC */, 5 /* HSYNC */, 21 /* PCLK */, 39 /* R0 */, 40 /* R1 */, 41 /* R2 */, 42 /* R3 */, 2 /* R4 */, 0 /* G0/P22 */, 9 /* G1/P23 */, 14 /* G2/P24 */, 47 /* G3/P25 */, 48 /* G4/P26 */, 3 /* G5 */, 6 /* B0 */, 7 /* B1 */, 15 /* B2 */, 16 /* B3 */, 8 /* B4 */
);

Arduino_ST7701_RGBPanel *gfx = new Arduino_ST7701_RGBPanel(
    bus, GFX_NOT_DEFINED /* RST */, 0 /* rotation */,
    true /* IPS */, 480 /* width */, 480 /* height */,
    st7701_type1_init_operations, sizeof(st7701_type1_init_operations),
    true /* BGR */);

TAMC_GT911 ts = TAMC_GT911(I2C_SDA_PIN, I2C_SCL_PIN, TOUCH_INT, TOUCH_RST, max(TOUCH_MAP_X1, TOUCH_MAP_X2), max(TOUCH_MAP_Y1, TOUCH_MAP_Y2));

Audio audio;

int touch_flag = 0;
int touch_x = -1;
int touch_y = -1;

void setup()
{

    Serial.begin(115200);

    // TFT init
    gfx->begin();
    gfx->fillScreen(WHITE);

    // Touch init
    pinMode(TOUCH_RST, OUTPUT);
    delay(100);
    digitalWrite(TOUCH_RST, LOW);
    delay(1000);
    digitalWrite(TOUCH_RST, HIGH);
    delay(1000);

    Wire.begin(I2C_SDA_PIN, I2C_SCL_PIN);
    ts.begin();
    ts.setRotation(TOUCH_ROTATION);

    // File init
    SPI.begin(SD_SCK, SD_MISO, SD_MOSI);
    if (!SD.begin(SD_CS))
    {
        Serial.println(F("ERROR: SD Mount Failed!"));
    }

    wifi_config_read();

    // 不能设为同优先级，不然可能跳过同级有限的任务
    // 需要有个0优先级的来刷新看门狗
    xTaskCreatePinnedToCore(Task_TFT, "Task_TFT", 20480, NULL, 0, NULL, 0);
    xTaskCreatePinnedToCore(Task_Touch, "Task_Touch", 2048, NULL, 1, NULL, 0);
}

void loop()
{
}

void Task_TFT(void *pvParameters) // This is a task.
{
    while (1)
    {
        page_main();
        Serial.println(F("Task_TFT"));
        vTaskDelay(100);
    }
}

void Task_Touch(void *pvParameters) // This is a task.
{
    while (1)
    {
        ts.read();
        if (touch_flag == 0)
        {
            if (ts.isTouched)
            {
                for (int i = 0; i < ts.touches; i++)
                {
                    touch_x = map(ts.points[0].x, TOUCH_MAP_X1, TOUCH_MAP_X2, 0, 480 - 1);
                    touch_y = map(ts.points[0].y, TOUCH_MAP_Y1, TOUCH_MAP_Y2, 0, 480 - 1);

                    // Serial.print("Touch ");
                    // Serial.print(i + 1);
                    // Serial.print(": ");
                    // ;
                    // Serial.print("  x: ");
                    // Serial.print(ts.points[i].x);
                    // Serial.print("  y: ");
                    // Serial.print(ts.points[i].y);
                    // Serial.print("  size: ");
                    // Serial.println(ts.points[i].size);
                    // Serial.println(' ');
                }
                // 多读一次，清空脏数据，不过好像没啥用
                ts.read();
                ts.isTouched = false;
                touch_flag = 1;

                Serial.print("  touch_x: ");
                Serial.print(touch_x);
                Serial.print("  touch_y: ");
                Serial.println(touch_y);
            }
        }

        if (touch_flag == -1)
            vTaskDelete(NULL);

        vTaskDelay(100);
    }
}

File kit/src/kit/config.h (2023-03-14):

#ifndef MF_CONFIG_H
#define MF_CONFIG_H

#include <SPI.h>
#include <FS.h>
#include <Wire.h>
#include <SD.h>
#include <Audio.h>
#include <Arduino_GFX_Library.h>
#include <TAMC_GT911.h>
#include <ArduinoJson.h>
#include <HTTPClient.h>
#include <Adafruit_MLX90640.h>
#include <Adafruit_SGP30.h>
#include <Adafruit_SHT31.h>
#include <ESPAsyncWebServer.h>

#include "JpegFunc.h"

// SD
#define SD_SCK 12
#define SD_MISO 13
#define SD_MOSI 11
#define SD_CS 10

// I2S
#define I2S_DOUT 19
#define I2S_BCLK 20
#define I2S_LRCK 46

// Touch
#define I2C_SDA_PIN 17
#define I2C_SCL_PIN 18
#define TOUCH_INT -1
#define TOUCH_RST 38

#define TOUCH_ROTATION ROTATION_NORMAL
#define TOUCH_MAP_X1 480
#define TOUCH_MAP_X2 0
#define TOUCH_MAP_Y1 480
#define TOUCH_MAP_Y2 0

#define B_NUM_MAIN 4
#define B_COUNTY_NUM 8

#define SSID "Makerfabs"
#define PWD "20160704"

// MLX90640
#define MLX_I2C_ADDR 0x33

#endif

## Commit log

2023-02-04 Add hardware
    [ESP32-S3 Parallel TFT with Touch 4.0“ ST7701 v1.2.brd, ESP32-S3 Parallel TFT with Touch 4.0“ ST7701 v1.2.sch]
2023-03-07 Add schematic PDF file
2023-03-09 多线程bug修复
2023-03-14 调整文件夹结构
    [stand.stl]

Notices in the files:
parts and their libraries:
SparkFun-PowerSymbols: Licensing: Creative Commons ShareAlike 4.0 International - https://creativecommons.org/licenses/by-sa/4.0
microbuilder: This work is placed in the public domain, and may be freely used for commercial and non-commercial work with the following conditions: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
